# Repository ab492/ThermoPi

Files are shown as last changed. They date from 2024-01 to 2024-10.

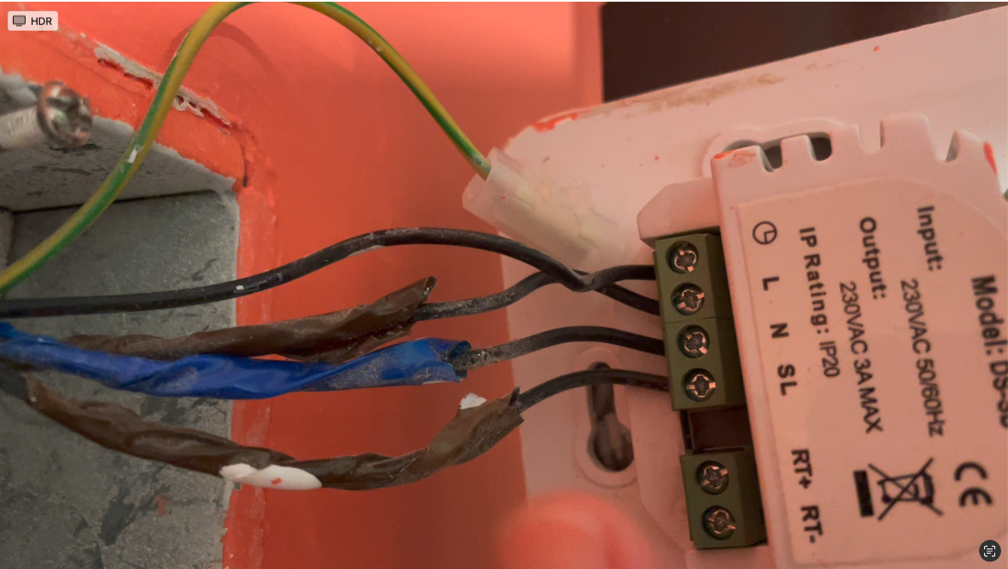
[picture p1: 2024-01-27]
documentation/original_heating_system/001_Thermostat_OriginalWiring.jpeg

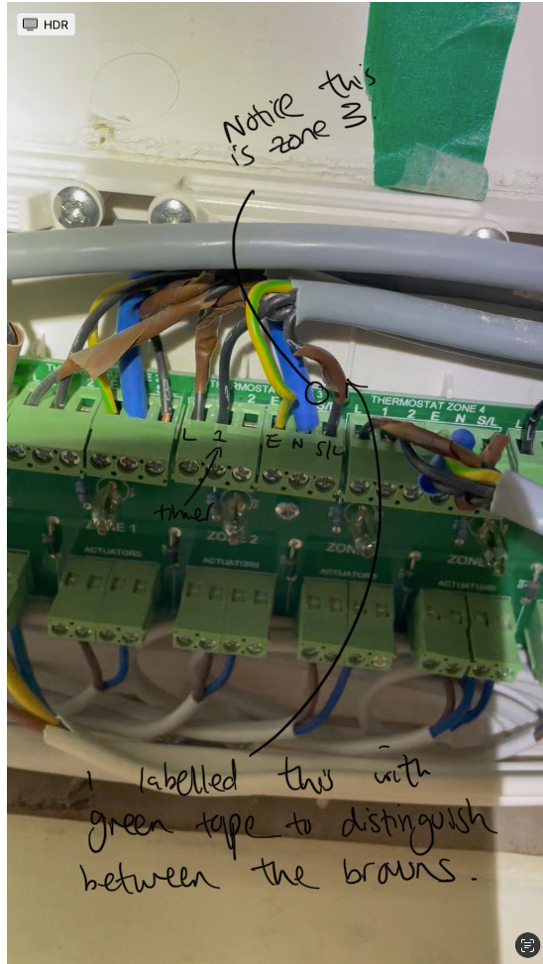
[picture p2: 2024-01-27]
documentation/original_heating_system/002_UFH_Original_Wiring_Annotated.jpeg

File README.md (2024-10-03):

# ThermoPi

ThermoPi is my smart thermostat project. It's a constant work in progress, used as opportunity to learn more about smart home green technology.

I've started writing up how I built it in a blog series [here](https://maverickprogramming.com/blog/how-to-build-a-smart-thermostat-part-1).

It's designed and tested on a Raspberry Pi (Raspberry Pi 3 Model B Rev 1.2).

# Working Notes
> Note: Everything below here are my working notes, used to document the code for my own future use.

## Getting Started

1. Clone the repo.
2. Copy `.env.template` to your local machine, rename to `.env` and update the values.
3. Install posgres with `sudo apt install postgresql`. See [Postgres Database](#postgres-database) for more details.
4. Run `python3 -m venv venv` to set up a virtual environment. If that doesn't work, run `sudo apt install python3-venv` to install `venv`.
5. Run `source venv/bin/activate` to activate `venv`.
6. Run `pip install -r requirements.txt` to install package dependencies.
7. Run `smart_thermostat.py` to start running the thermostat.

In reality, you want `smart_thermostat.py` to run on launch of the Pi automatically. You can set it up to run as a system service using the [template](service_files/thermostat.service).

There are some helpful [MAKE commands](Makefile) you can use to help.

## Thermostat
This is the core functionality of `ThermoPi` and is designed to work without an internet connection (local network required for access) and without the 'smart' elements like HomeKit integration and API tracking.

### Installing The Temperature Sensor
1. As sudo, add the following line to `/boot/config.txt`. This enables the 1-Wire interface on the GPIO pin used by the sensor. 
```
dtoverlay=w1-gpio
```
2. As sudo, add the following to `/etc/modules`. This ensures that the necessary modules are loaded at boot.
```
w1-gpio
w1-therm
```

### Setting Up The Relay
1. If you're using an unprivileged user, you'll need to run the following the grant permission to access the GPIO pins:
```
sudo adduser your-user gpio
```

## HomeKit Integration
I used [HAP-python](https://github.com/ikalchev/HAP-python) for my HomeKit integration.

Whilst developing with `HAP-python`, here are a few discoveries I made that might be useful in future debugging. These notes have been incorporated into the system, but I'm keeping them here for the record.

1. Use an unprivaledged user when running this startup script. 
2. Don't bother using "Wait for network" or their suggested fix: I couldn't get either working. I ended up using a 30 second wait, but this might be worth re-assessing in the future.
3. Initially I got errors about accessing temporary files; I believe this was linked to setting relative paths within my Python scripts. Adding `WorkingDirectory=/home/developer/ThermoPi` seemed to help the service run without errors.

## Postgres Database
I used a Postgres database for data logging. The thermostat *should* run without a database setup because the error logger just reports errors, but I've not tested this thoroughly. Aside from installing Postgres, you'll need to have a table `temperature_logs` with the correct fields as per `database.py`. After creating the database you'll need to create a user with all privileges that matches the name of the user account (`developer`). See [postgres.md](documentation/postgres.md) for details and commands.

## Useful Articles
- https://pimylifeup.com/raspberry-pi-temperature-sensor/
- https://thepihut.com/blogs/raspberry-pi-tutorials/ds18b20-one-wire-digital-temperature-sensor-and-the-raspberry-pi

## TODO List
- Look into smarter temperature control. Due to the way underfloor heating works, it continues heating the room once the target temperature has been met. Look into calculating the rate of change in order to predict when to turn the heating element off.
- Add an offline override if using the temperature sensor in a main room.
  
## Bugs
- When initially powering on the device the target temperature is logged as 10 even though it’s set higher. Once the thermostat is turned on and updated it's reported correctly. Seems to be an issue with reporting initial state.

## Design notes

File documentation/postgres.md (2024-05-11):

# Postgres Helper

### How to install

`sudo apt update`
`sudo apt install postgresql`
`sudo systemctl start postgresql // Start service`   
`sudo systemctl enable postgresql // Enable service on launch`    

### Helper commands

Switch to postgres admin user: `sudo -i -u postgres`
Exit postgres user: `exit`
Enter psql prompt: `psql` or `psql -U developer -d thermodb`  or `psql -U postgres` 
Connect to database: `\c thermodb`
Describe tables: `\dt`
Describe specific table (i.e. temperature_logs): `\d temperature_logs`
Exit psql prompt: `\q`

### Creating a peer user

By default this user peer authentication, where the database user needs to match the name of the current account user.

For example, from the sudo account I ran:

`sudo su - postgres`
`psql` 

Then ran the following to create the peer user:

`CREATE DATABASE thermodb;`

`CREATE USER thermodev WITH PASSWORD 'some_password';` (including `'`)

`GRANT ALL PRIVILEGES ON DATABASE thermodb TO thermodev;`

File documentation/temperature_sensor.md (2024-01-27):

# Temperature Sensor

This system has been designed for DS18B20 temperature sensors. I've used two types during development.

## Waterproof DS18B20

This [URL](https://medium.com/@paulo.de.jesus/regulate-temperature-with-a-raspberry-pi-pico-part-2-assembly-647f2a10fdd8) was helpful for identifying which cable was which. Here they are:

| Cable | Type | 
|---|---|
| Red | + |
| White  | - |
| Yellow | Data |

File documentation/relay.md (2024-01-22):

In order to control the heating system with the Raspberry Pi I need to use a relay.

## What is a relay?
A relay is an electrically operated switch which allows you to control a high power circuit (like the heating system) with a low powered circuit (like one powered by the Raspberry Pi). Relays consist of an electromagnet and a switch: when electric current passes through the coil of the electromagnet, it creates a magnetic field that connects the switch.

## NO or NC
A relay has two options for controlling a circuit: Normally Open (NO) or Normally Closed (NC). For something like a thermostat, we want the circuit to be normally open (i.e. the circuit is broken) since we don't want a thermostat on all the time. When we want it on, we'll energise the relay which will connect the normally open circuit to common and complete the circuit, thus turning our thermostat on.

## Which Relay to Use?
I've chosen a Waveshare 3 terminal relay, since at most I'll want to control the temperature in 3 zones (for now). The key information about this relay is that it's suitable for high power circuits, being able to work with loads up to 5A 250V AC or 5A 30V DC.

It's also important to note that this is low active, meaning that setting low turns the relay on.

## Replacing the Thermostat
In the back of the existing thermostat where 4 cables: a timer, live (L), switched live (SL) and neutral (N).

Live and neutral allow the thermostat to be powered (giving it the ability to have a complete circuit) and the switched live is this missing piece of the circuit that is completed when the thermostat needs to turn the boiler on. 

For my purposes, I only needed two of these cables: switched live will be in the NO connection of my relay since the default is no connection; live will go into the common port of my relay. When I energise the relay, it'll complete the circuit between live and switched live and turn the heating on.

## Relay Specific Info

| Channel No. | BCM | 
|---|---|
| CH1 | 26 |
| CH2 | 20 |
| CH3 | 21 | 

[Original Link](https://thepihut.com/products/raspberry-pi-relay-board)
[Wiki Information](https://www.waveshare.com/wiki/RPi_Relay_Board)
[Manufacturer Information](https://www.waveshare.com/rpi-relay-board.htm)

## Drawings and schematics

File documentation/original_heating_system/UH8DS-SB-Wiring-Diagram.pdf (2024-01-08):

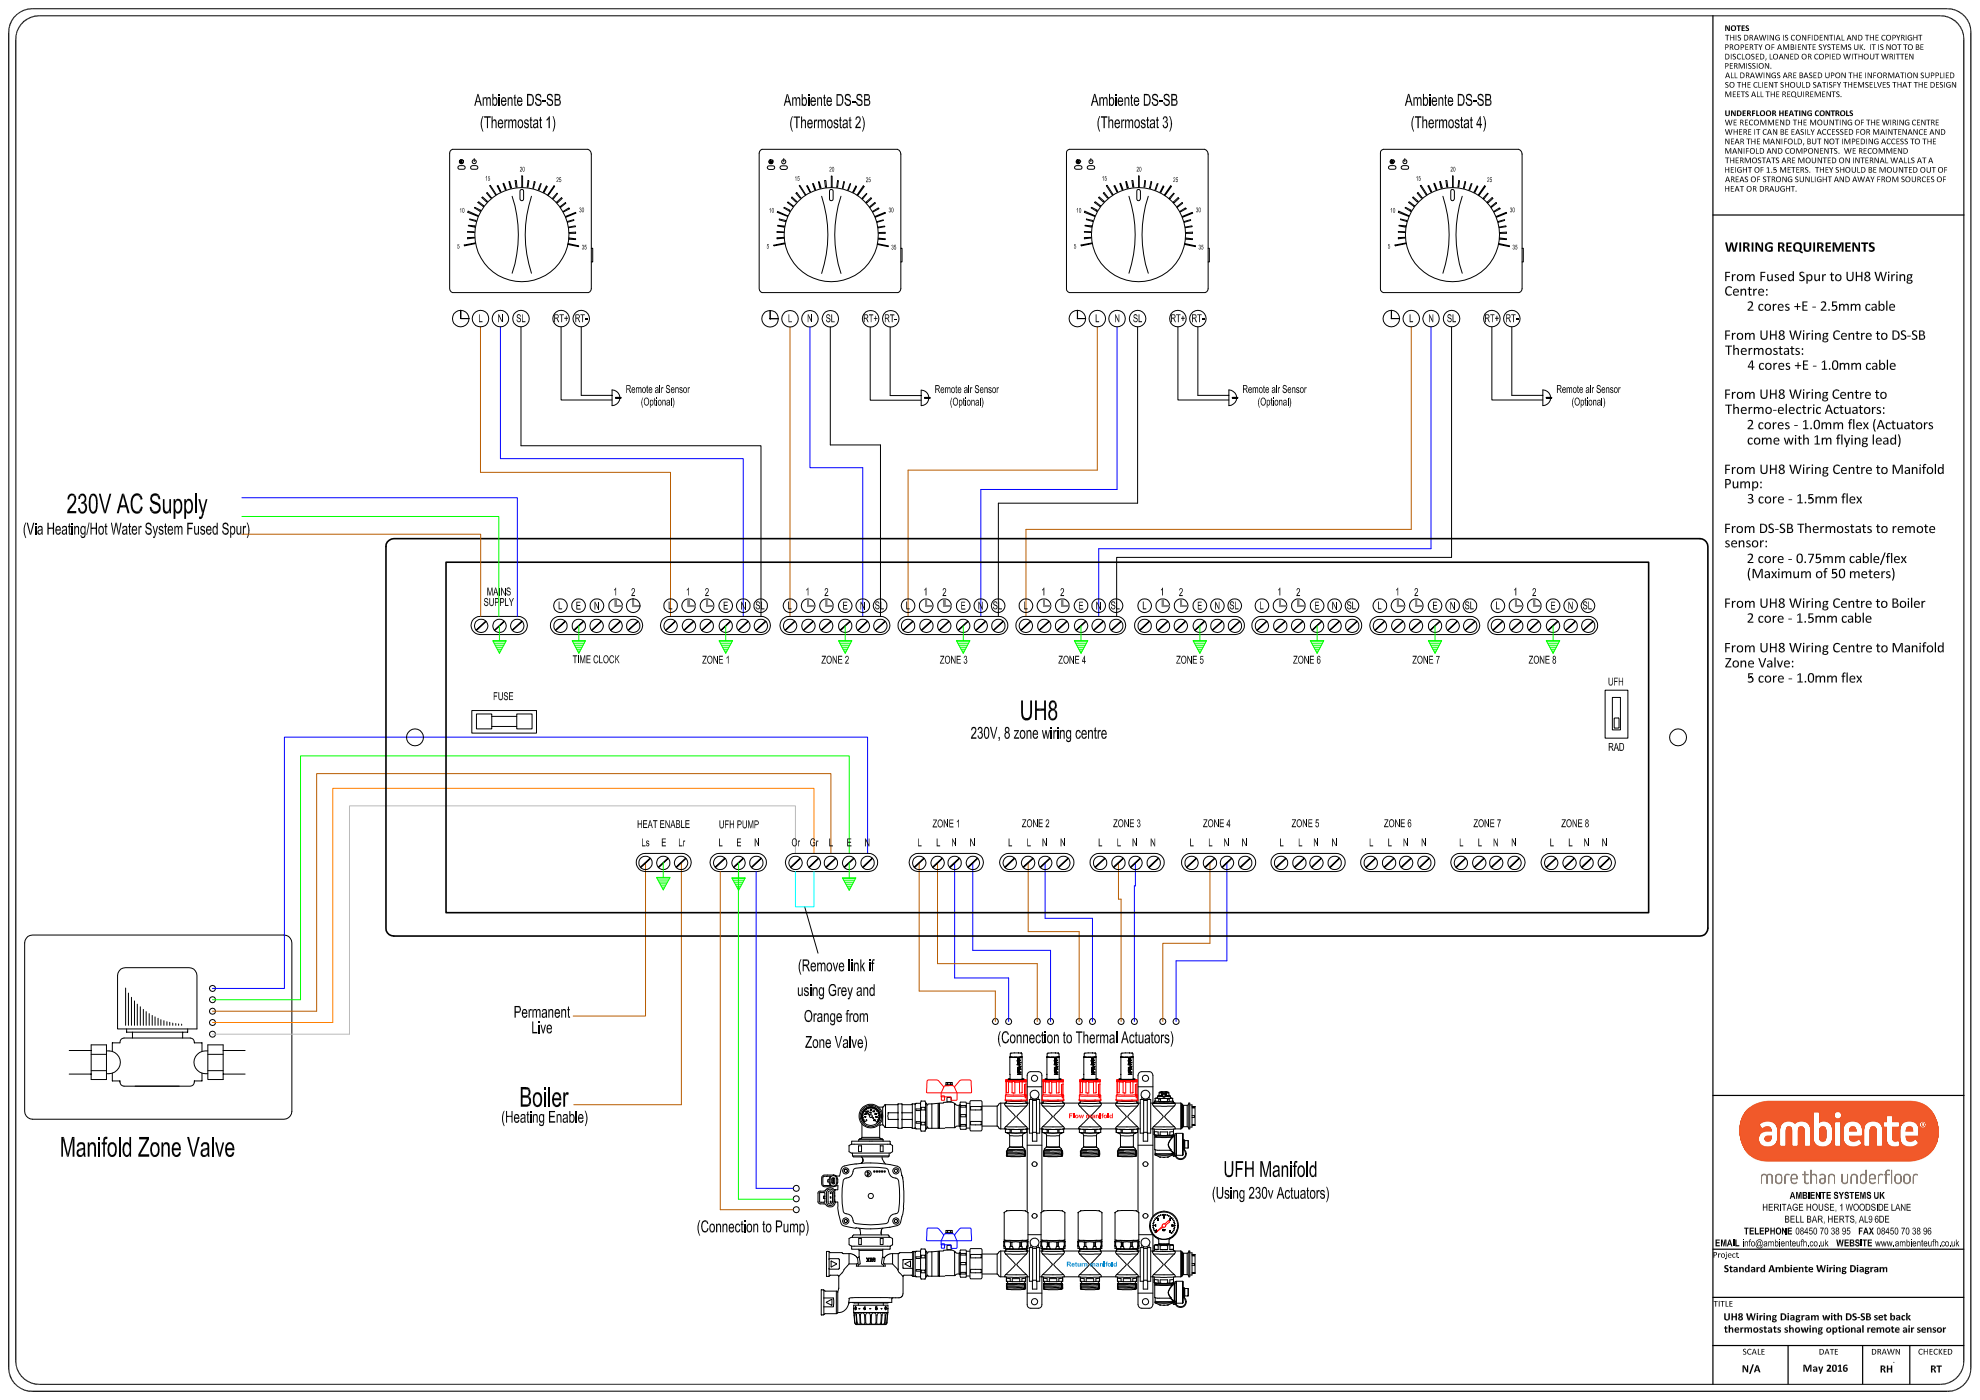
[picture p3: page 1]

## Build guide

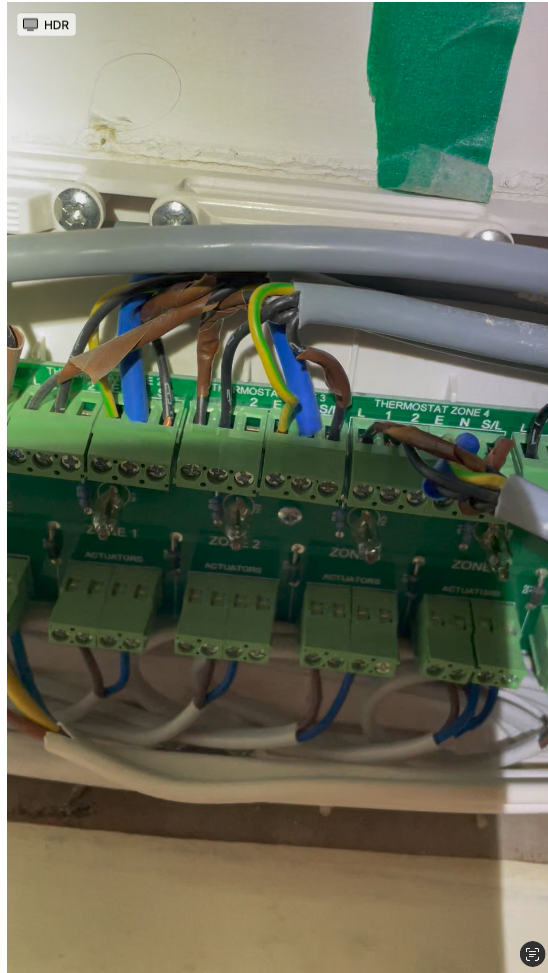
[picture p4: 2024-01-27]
documentation/original_heating_system/002_UFH_Original_Wiring.jpeg

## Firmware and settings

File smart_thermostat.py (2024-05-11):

import argparse
import asyncio
from utils.thermostat import Thermostat
from utils.relay import Relay
from utils.homekit_thermostat import HKThermostat, TargetHeatingCoolingState
from utils.data_logger import DataLogger
import time
from pyhap.accessory_driver import AccessoryDriver
import signal
from enum import Enum, unique
import logging

logging.basicConfig(level=logging.INFO, format='%(asctime)s - %(name)s - %(levelname)s - %(message)s')

class SmartThermostat:
    """
    Sets up a smart thermostat. The key purpose is to coordinate between the 'dumb' thermostat (`thermostat.py`) and the HomeKit integration (`homekit_thermostat.py`).
    
    Note: All temperature is handled in celcius.

    Key Attributes:
        _heating_relay (Relay): Relay object controlling the heating element.
        _target_temperature_celcius (float): Desired temperature in Celsius. Defaults to 20.0°C.
        _hysteresis (float): Temperature leeway in determining when to activate/deactivate the relay. Set to 0.5°C.

    Methods:
        set_target_temperature_celcius(temperature): Sets a new target temperature.
        start_thermostat(): Starts the control loop in an asynchronous task to monitor and control temperature.
        register_for_temperature_did_change_notification(callback): Registers a callback to be invoked with the latest temperature reading.
        start_monitoring_current_temperature(): If you've registed for notifcations, this starts the observation process for current temperature.
        shutdown(): Performs cleanup actions, particularly for GPIO resources used by the relay. Once shutdown has been called, you cannot restart.
    """
    
    # Initialization

    def __init__(self, loop):
        self._logger = logging.getLogger(__name__)
        self.loop = loop
        self.thermostat_task = None
        self.driver_task = None

        # Setup thermostat
        relay = Relay(pin=26)
        self.thermostat = Thermostat(relay)
        self.thermostat.register_for_temperature_did_change_notification(self.thermostat_temperature_did_change)
        
        # Setup HomeKit integration
        self.driver = AccessoryDriver(port=51826, loop=self.loop)
        self.homekit_thermostat = HKThermostat(self.driver, "Office Thermostat")
        self.homekit_thermostat.register_for_heating_cooling_state_did_change_notifications(self.heating_cooling_state_did_change)
        self.homekit_thermostat.register_for_target_temperature_did_change_notifications(self.target_temperature_did_change)
        self.driver.add_accessory(accessory=self.homekit_thermostat)
        signal.signal(signal.SIGTERM, self.driver.signal_handler)
        
        self.data_logger = DataLogger(zone=3)
        
    # Public Methods
        
    async def start_thermostat(self):
        self._logger.info("Starting HomeKit integration...")
        self.driver_task = asyncio.create_task(self.driver.async_start())  
        await self.thermostat.start_monitoring_current_temperature()
        
        self.data_logger.set_temperature_callback(self.thermostat.current_temperature_celcius)
        self.data_logger.set_target_temperature_callback(self.thermostat.target_temperature_celcius)
        self.data_logger.set_is_active_callback(self.thermostat.is_active)
        await self.data_logger.log_data_periodically()
        
        
    async def shutdown(self):
        self._logger.info("Shutting down thermostat...")

      # Cancel and await the thermostat task if it exists
        await self._cancel_and_await_task(self.thermostat_task, "Thermostat")
        await self.thermostat.shutdown()
        self.thermostat_task = None  # Reset the task to None after cancellation
            
        # Cancel and await the driver task if it exists
        await self._cancel_and_await_task(self.driver_task, "Driver")
        self.driver_task = None  # Ensure the task reference is cleared
        
    def thermostat_temperature_did_change(self, new_temperature):
        self._logger.info("Current temperature did change to: %s°C. Updating HomeKit.", new_temperature)
        self.homekit_thermostat.set_current_temperature(new_temperature)
    
    def heating_cooling_state_did_change(self, new_state):
        self._logger.info("HomeKit heating cooling state did change to: %s. Updating Thermostat.", new_state)
        
        # Cancel any existing thermostat task before starting a new action
        if self.thermostat_task:
            self.thermostat_task.cancel()
            self.thermostat_task = None  # Clear the existing task
            
        # Depending on the new state, schedule the start or stop coroutine
        if new_state in (TargetHeatingCoolingState.HEAT, TargetHeatingCoolingState.AUTO):
            # Schedule the thermostat start coroutine without waiting for it
            self.thermostat_task = asyncio.create_task(self.thermostat.start())
        elif new_state in (TargetHeatingCoolingState.OFF, TargetHeatingCoolingState.COOL):
            # Schedule the thermostat stop coroutine without waiting for it
            self.thermostat_task = asyncio.create_task(self.thermostat.stop())
            
    def target_temperature_did_change(self, new_temperature):
        self._logger.info("HomeKit target temperature did change to: %s. Updating Thermostat.", new_temperature)
        self.thermostat.set_target_temperature_celcius(new_temperature)
        
    # Private Methods
   
    async def _cancel_and_await_task(self, task, task_name):
        """
        Cancels the given asyncio Task and waits for it to finish.

        Arguments:
            task (asyncio.Task): The asyncio Task to cancel and await.
            task_name (str): The name of the task for logging purposes.
        """
        if task is not None:
            task.cancel()
            try:
                await task
            except asyncio.CancelledError:
                self._logger.info(f"{task_name} task cancelled.")
            except Exception as e:
                self._logger.error(f"Error stopping {task_name} task: {e}", exc_info=True)
                
if __name__ == "__main__":
    loop = asyncio.new_event_loop()
    asyncio.set_event_loop(loop) # This sets the global event loop and prevents clashing between HAP-Python asyncio.
    controller = SmartThermostat(loop)

    try:
        loop.run_until_complete(controller.start_thermostat())
        loop.run_forever()  # Keep the loop running
    except KeyboardInterrupt:
        pass  # Handle keyboard interrupt
        logging.info("Program terminated by user.")
    except Exception as e:  # Catching other exceptions
        logging.error(f"Unexpected error: {e}", exc_info=True)  # Log the error with stack trace
    finally:
        logging.info("Shutting down gracefully...")
        loop.run_until_complete(controller.shutdown())  # Ensure everything is stopped properly
        loop.close()

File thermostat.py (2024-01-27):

from utils.relay_utils import Relay
from utils.temperature_utils import read_temp
import time 
## todo: check less than or equal is working
## add threshold measurements
## add unit tests!
## add note that all values are celcius

class Thermostat:
    def __init__(self, relay_pin):
        self._heating_relay = Relay(relay_pin)
        self._hysteresis = 0.5
        
    @property
    def current_temperature(self):
        current_temperature = read_temp()
        return current_temperature.celcius
    
    @property
    def target_temperature(self):
        return self._target_temperature
    
    @property
    def is_active(self):
        return self._heating_relay.is_active
    
    def set_target_temperature(self, temperature):
        self._target_temperature = temperature
        
    def start(self):
        try:
            # Continuously check and control the temperature
            while True:
                self._check_and_control_temperature()
                time.sleep(3)  # Wait for 3 seconds before checking again
        except KeyboardInterrupt:
            print("Terminating the thermostat control.")
        finally:
            self.stop()
        
    def _check_and_control_temperature(self):
        print(f"Current temp: {self.current_temperature}")
        if not self.is_active and self.current_temperature < (self.target_temperature - self._hysteresis):
            print(f"Current temperature ({self.current_temperature}°C) below target temperature ({self.target_temperature}°C). Turning thermostat ON.")
            self._heating_relay.turn_on()
        elif self.is_active and self.current_temperature > (self.target_temperature + self._hysteresis):
            print(f"Current temperature ({self.current_temperature}°C) above target temperature ({self.target_temperature}°C). Turning thermostat OFF.")
            self._heating_relay.turn_off()
  
    def stop(self):
        self._cleanup()
        
    def _cleanup(self):
        self._heating_relay.cleanup()
        
# Example usage
if __name__ == "__main__":
    # Define the GPIO pin for the relay and the temperature threshold
    relay_pin = 26
    thermostat = Thermostat(relay_pin)
    thermostat.set_target_temperature(22)
    thermostat.start()

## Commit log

2023-11-28 Add ability to send temperature to API
2024-01-25 Add better error handling
    [temperature_utils.py]
2024-01-27 Add basic temp sensor layout
    [001_BasicTempSensorLayout.fzz]
2024-02-05 Make temperature utils async await compatible
2024-05-02 Switch to asyncio
2024-05-08 WIP data logger and error handling
    [data_logger.py, smart_thermostat.py, weather_api.py]
2024-05-10 Add database error handling
    [database.py, smart_thermostat.py]
